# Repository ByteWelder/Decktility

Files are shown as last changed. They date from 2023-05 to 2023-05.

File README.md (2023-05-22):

# Decktility

Decktility is a handheld PC, inspired by [Yarh.io Micro 2](https://yarh.io/),
[uConsole](https://www.clockworkpi.com/uconsole) and various retro handheld PCs.

It is built with a Raspbery Pi CM4 and an 800x480 pixel IPS screen with capacitive touch.
A set of batteries is estimated to provide about 6 hours of power. (\*)

The original build log and learnings can be found on [ByteWelder.com](https://bytewelder.com/posts/2023/05/20/building-a-handheld-pc.html).

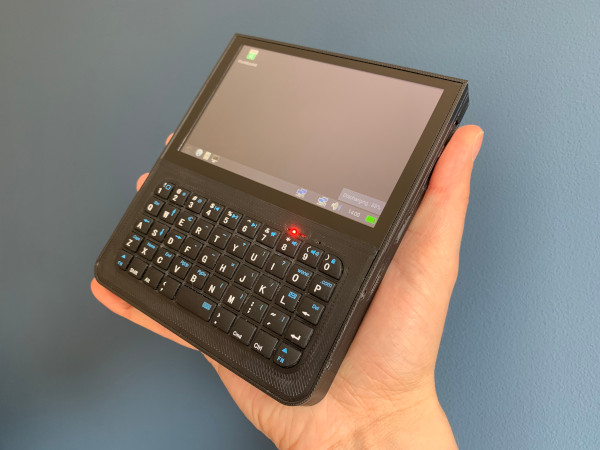
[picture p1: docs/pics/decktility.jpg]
Decktility device mockup


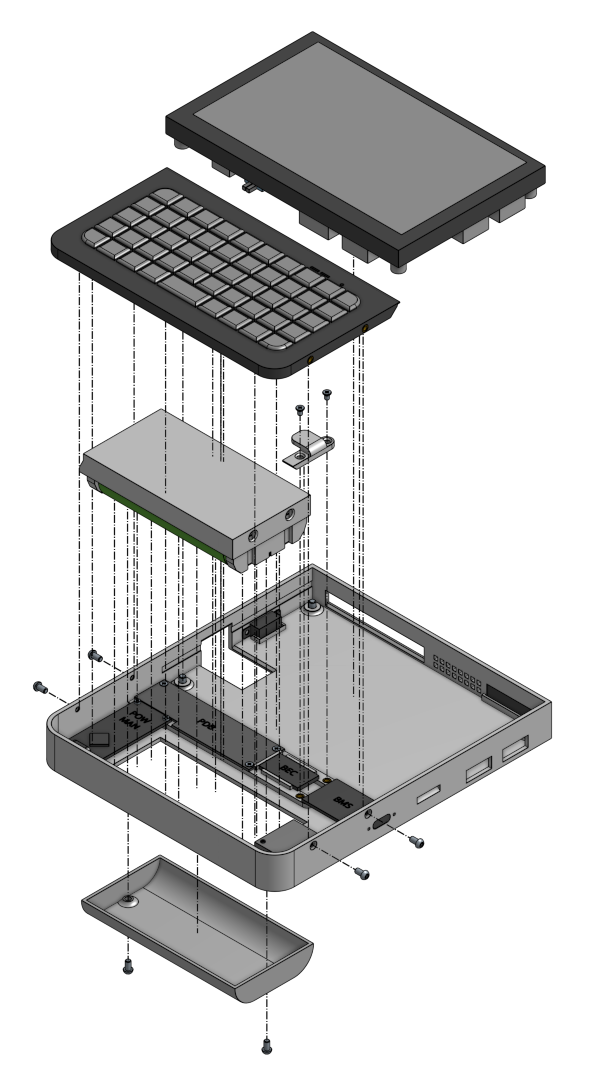
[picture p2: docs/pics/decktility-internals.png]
Decktility device mockup


# Features & Specifications

- Compact design: `124.4 x 144.0 x 16.3 mm` (w x h x d). The battery lid portrudes by `10.2 mm`.
- Weighs approximately `375 g`. (depends on filament weight)
- Powered by a Raspberry Pi CM4 and a BTT Pad 5 (`800x480` resolution with capacitive touch)
- Replaceable batteries
- USB-C charging (~`10 W`)
- Power management

(\*) Using US18650VTC6 cells. Power draw was tested with an idle Discord tab in Chrome.

# Software

## Raspberry Pi

The Pi can be used with [Raspberry Pi OS](https://www.raspberrypi.com/software/) or any other Pi-compatible OS.

Check the to the [Pad 5 Manual](https://github.com/bigtreetech/Raspberry-Pad/tree/master/Pad5) for installing the OS and setting up some of the hardware.

## Arduino Nano / Power Manager

The [Power Manager](./powermanager) controls the power connection to the Pi and the keyboard. Power is enabled/disabled depending on the battery voltage.
The power manager measures battery and charging status, and can send it to the Pi. This enables battery status on the Pi desktop.
If something is not clear - or if you find an error, please open an issue on the GitHub project page.

Check out the [assembly guide](docs/assembling.md) for more details.

# Case

The latest printable parts are in the [printables](printables) folder.

The case is available as open hardware via OnShape:
- [v1.1](https://cad.onshape.com/documents/bcf3b5212bb2ba6496cfe6cf/v/382999b629ab56cddd2b7e21/e/5dfdd5987e1df112fcfa814b)
- [Main/WIP](https://cad.onshape.com/documents/bcf3b5212bb2ba6496cfe6cf/w/d70be68a60b4c80f684ba746/e/f2fb47dfa2dbdc91d7666ed1)

**Warning**: Don't print from the Main branch, because it will possibly have unfinished and/or untested changes.

# Building

Build this project at [your own risk](LICENSE.md).
The build guide might have flaws.
Working with batteries and electronics is not without risk.

- [Bill of materials](docs/bom.md)
- [Printing guide](docs/printing.md)
- [Assembling](docs/assembling.md)

# License

All hardware, software and other content in this project are licensed under `Attribution-ShareAlike 4.0 International (CC BY-SA 4.0)`.

See [LICENSE.md](LICENSE.md) for details. For a short overview and translations go to the [Creative Commons website](https://creativecommons.org/licenses/by-sa/4.0/legalcode).

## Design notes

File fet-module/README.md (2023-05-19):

This is the KiCad project for the FET board, which acts as an electronic switch to turn on/off the hardware depending on available battery power.

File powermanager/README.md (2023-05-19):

This is the Arduino project for the power manager firmware. Open it with Arduino IDE V2.

It is tested with Arduino Nano V3.0, but might also work with other types of Arduino hardware.
Other Arduino hardware is not tested/verified to work, and it will likely not fit on the case mounting points.

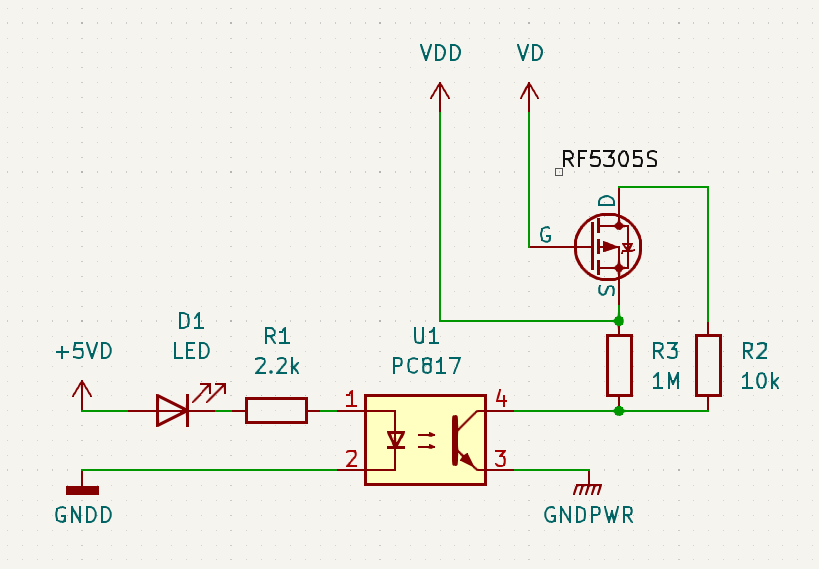
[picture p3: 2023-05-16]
docs/pics/fet-schematic.png

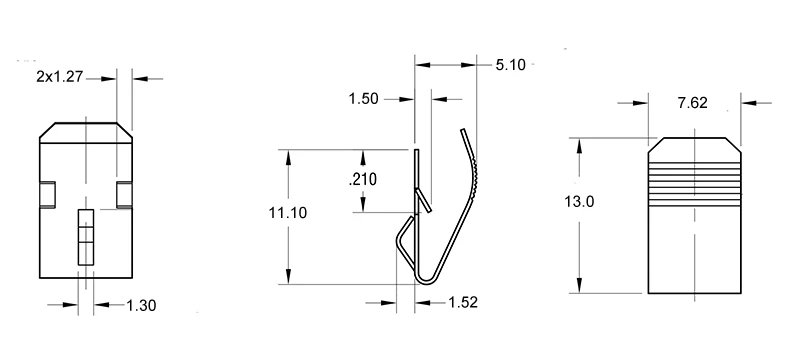
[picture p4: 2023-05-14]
docs/pics/battery-contact-schematic.webp

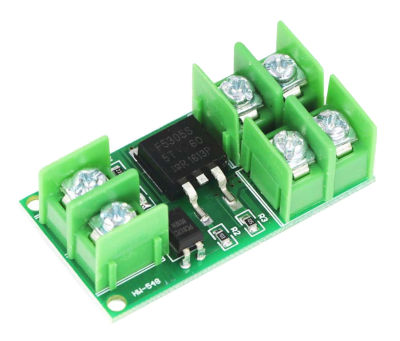
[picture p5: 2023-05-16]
docs/pics/fet-module.jpg

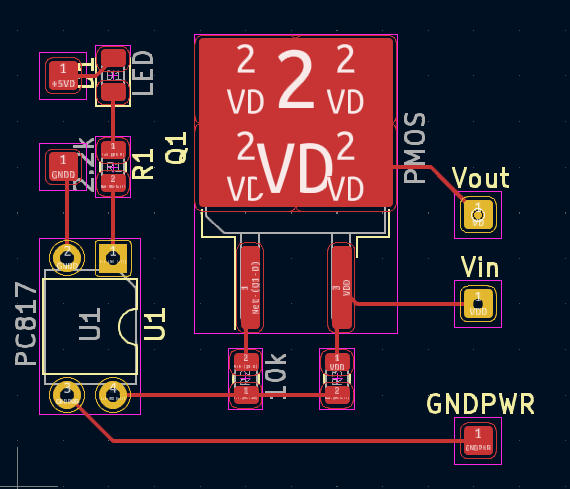
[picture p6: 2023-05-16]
docs/pics/fet-pcb.png

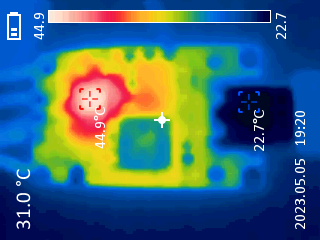
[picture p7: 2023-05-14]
docs/pics/usb-c-bms-heatmap.png

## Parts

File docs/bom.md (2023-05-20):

# Bill of materials for Decktility

I ordered many of the components from AliExpress.
Make sure to double-check that you're ordering the correct item.

- BigTreeTech Pad 5
- Raspberry Pi CM4
- Arduino Nano V3.0
- `5 V` `3 A` step down converter like [this](pics/step-down-top.jpg)
- USB-C 2S battery charger/BMS like [this](pics/usb-c-bms.jpg)
- BlueTooth mini keyboard like [this](pics/bluetooth-keyboard.jpg) (needs modding, see build guide)
- 2x 18650 battery. They **must** be capable of charging with a current of at least `1.5 A`. For example: `US18650VTC6`
- 4x Spring steel 18650 leaf spring battery contact like this [this](pics/battery-contacts.jpg)
- 50x M2 heat insert nut (`2 mm` high, `3.2 mm` wide) (you don't need 50, but you might need more than a single set in case of a failed print)
- 10x M1.4 2mm self-tapping screw (it's best to get a set with various sizes, because printing tolerances vary)
- A set of watch maker screws of various sizes (M1.0, M1.2, M1.4, etc.)
- 4x M2.5 4mm (button or flat head) for Pad 5 mounting (there are cheap sets with M2-M2.5-M3 screws out there)
- 2006 5V fan (`20 x 6 mm`)
- Electrical wire: 24 AWG for power and 28 AWG for silicon. (silicon, not plastic)
- SS12F15 mini slide switch
- Resistors: 1x `2.2M Ohm`, 1x `3.9M Ohm`
- Electronic switch control board (see below)
- Experiment PCB
- (optional) Elastic jewelry wire, 1mm, transparent ('optical fiber' to wire USB charger LEDs to case)
- (optional) JST-SH male and female plugs (for easy detaching I2C wires during development)
- A soldering iron with a long and thin tip to reach the bottom of the Pi header on the PCB. I used a TS100 C1 tip.
- Other soldering gear, 3D printer (or use a 3D printer service online).

## Electronic switch control board

I used a [module](pics/fet-module.jpg) that you can find on AliExpress/Amazon. The module itself is too large, 
so it needed to be transplanted onto an experiment board.
You could either buy such a module and transplant the components, or you can buy the components individually.

Check the assembly guide for the schematics.

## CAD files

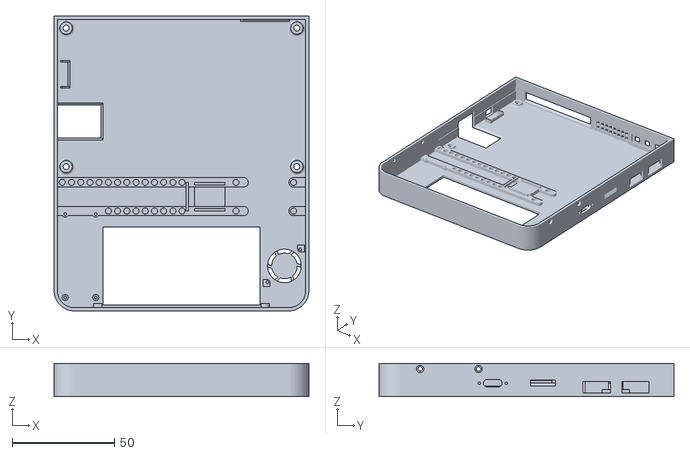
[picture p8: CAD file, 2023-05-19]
printables/Main Case.stl
124.4 x 144.0 x 16.3

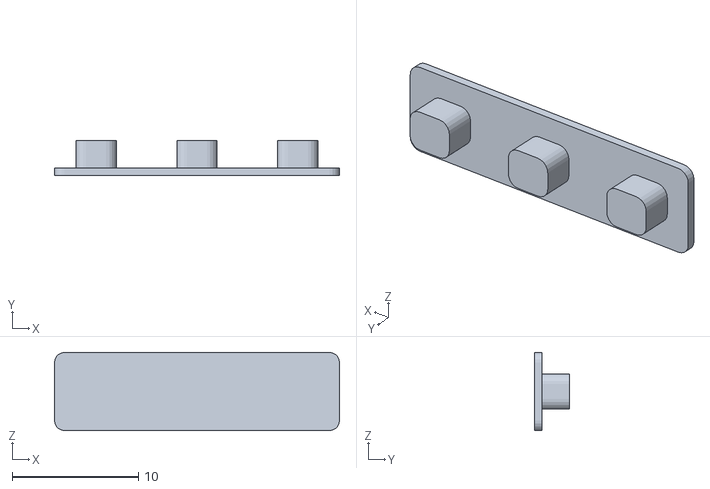
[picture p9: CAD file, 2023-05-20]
printables/Display buttons shim.stl
22.6 x 2.80 x 6.20

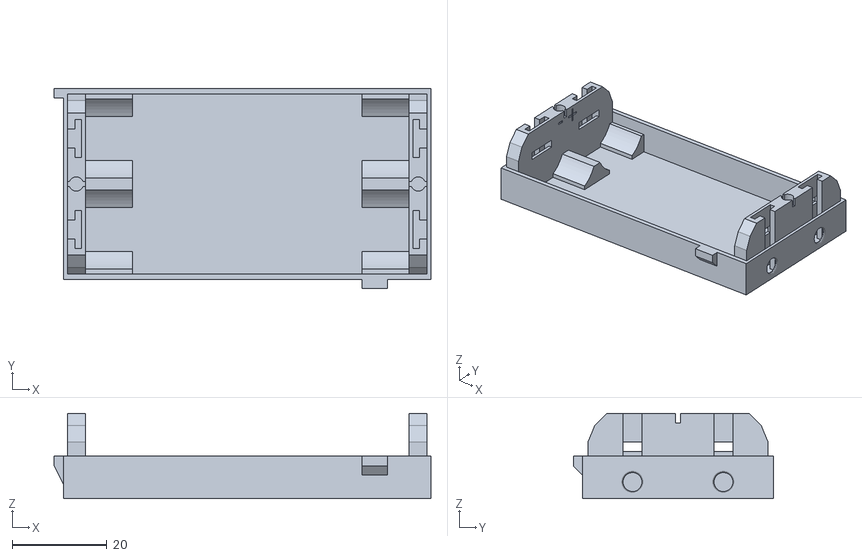
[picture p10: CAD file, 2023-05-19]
printables/Battery Tray.stl
79.6 x 42.3 x 18.0

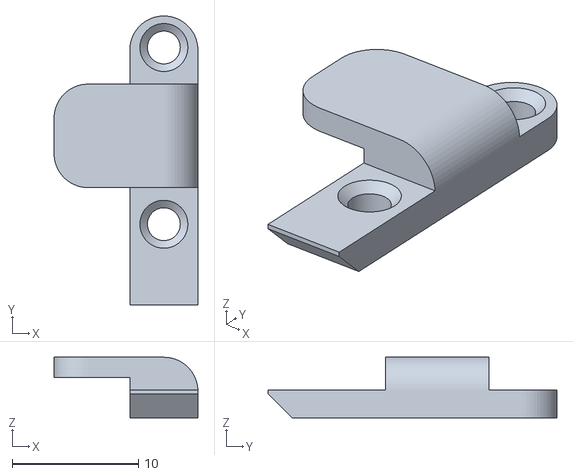
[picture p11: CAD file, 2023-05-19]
printables/Retainer.stl
11.4 x 22.9 x 4.80

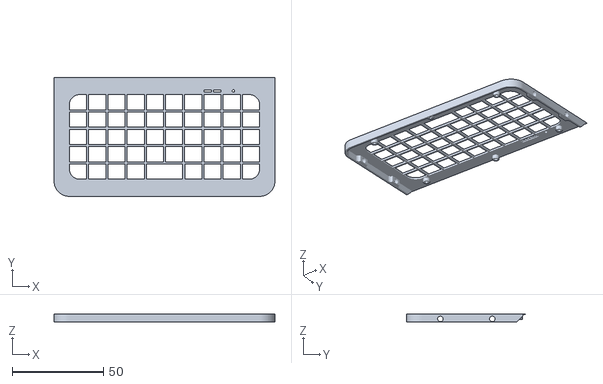
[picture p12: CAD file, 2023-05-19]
printables/Keyboard Panel.stl
121.2 x 65.1 x 4.50

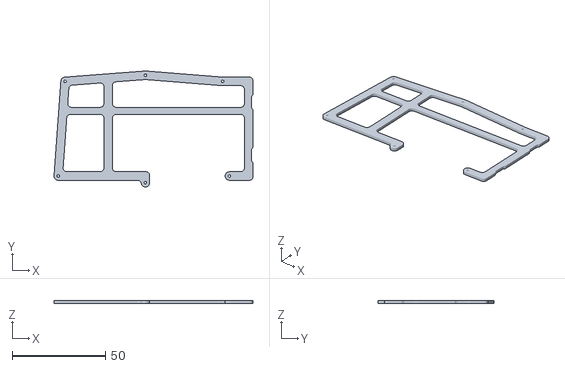
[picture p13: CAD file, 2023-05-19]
printables/Keyboard Retainer.stl
106.8 x 62.3 x 1.60

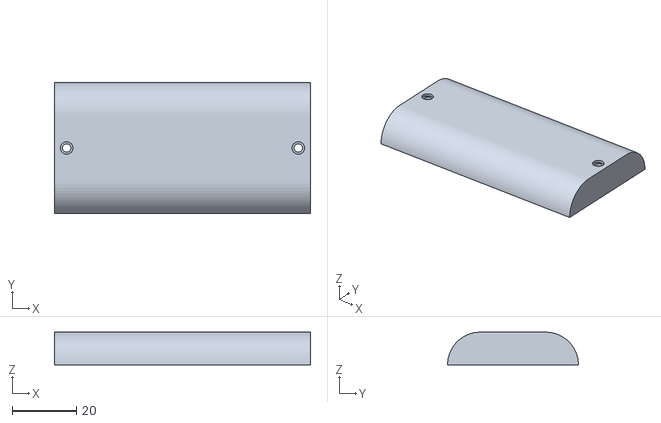
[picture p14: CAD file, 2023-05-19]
printables/Battery Cover.stl
79.8 x 40.8 x 10.2

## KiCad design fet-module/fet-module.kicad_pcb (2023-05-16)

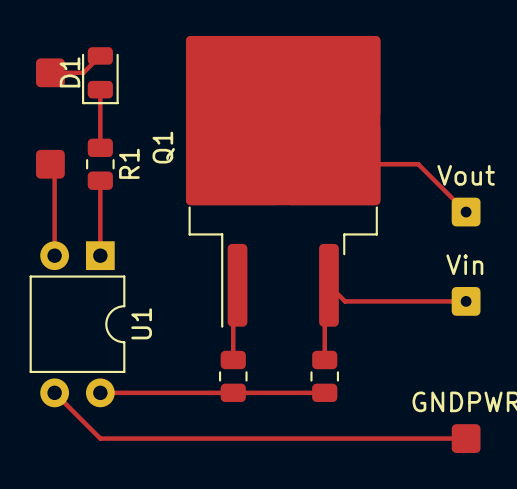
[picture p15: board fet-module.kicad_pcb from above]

Board: 2 copper layers, 11 parts (0 on the bottom side), 9 nets.

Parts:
+5VD: SolderWire-0.1sqmm_1x01_D0.4mm_OD1mm
D1: LED; LED_0805_2012Metric
GNDD: SolderWire-0.1sqmm_1x01_D0.4mm_OD1mm
GNDPWR: SolderWire-0.1sqmm_1x01_D0.4mm_OD1mm
Q1: PMOS; TO-263-2
R1: 2.2k; R_0805_2012Metric
R2: 10k; R_0805_2012Metric
R3: 1M; R_0805_2012Metric
U1: PC817; DIP-4_W7.62mm
Vin: SolderWire-0.1sqmm_1x01_D0.4mm_OD1mm
Vout: SolderWire-0.1sqmm_1x01_D0.4mm_OD1mm

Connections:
+5VD: +5VD.1, D1.2 (A)
GNDD: GNDD.1, U1.2
GNDPWR: GNDPWR.1, U1.3
unnamed: D1.1 (K), R1.1
unnamed: Q1.1 (D), R2.2
unnamed: R1.2, U1.1
unnamed: R2.1, R3.2, U1.4
VD: Q1.2 (G), Vout.1
VDD: Q1.3 (S), R3.1, Vin.1

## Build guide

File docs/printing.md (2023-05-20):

# Printing Guidelines for Decktility

The settings below are based on what I used in SuperSlicer (~PrusaSlicer).
They might (not) translate to other slicer software.

If you don't own a 3D printer yourself, you can use an [online service](https://duckduckgo.com/?t=ffab&q=online+3d+printing+service&ia=web).

The parts can be found in the [printables folder](../printables).

## Filament

If your 3D printer does not have an enclosure, use PETG or PCTG.
I prefer using ASA (with ABS/ABS+ as alternative).

Avoid using PLA or other similar low-temperature filaments:
The BMS can get hot (`45 C`, measured outside the case).
There is active cooling, but if the fan is defect, it might heat up the plastic and warp it.

## Printing

Some parts are exported from CAD upside-down and need to be flipped `180 degrees`.

You can print with layer height of `0.2 mm` or finer and a `0.4 mm` nozzle.

### PCB Bracket

Print in normal orientation with build plate supports.

### Battery Cover

Rotate it 90 degrees over the Y axis so it stands up on its side.
You need supports along the edge on this inside.
I painted them on manually, because they get attached to the inner wall.
Alternatively, you can use `Supports: Everywhere`.

Make sure you clean up the inside thoroughly, so it fits on the case.

### Main Case

Note that the walls are relatively thin and weaken the case near connector holes.
This means that your wall adhesion has to be good. Ensure you're running your filament at a high enough
temperature for the speed you're printing at. If you calibrated your filament to work at a minimum
tempearture, you might have to raise it to create sufficient strength.

Consider changing the the top layer fill patern to `Concentric`. This will give you smoother top surface quality,
both for mounting components and for the top edge of the case.

When printing the main case with ASA, I slice with manually added supports only. I place these supports at:
- The counterbores on the back (the ones for mounting the display)
- The ethernet bridging part
- The Pi's IO connector on the back

When printing with ASA, disable bridging fan speed to avoid adhesion problems near the connector openings.
Otherwise, layers might split off when placing the display into the case.

### Display Buttons Shim

This is printed in TPU. I used 95A shore hardness.
Use a layer height of `0.10 mm` and ensure you have sufficient adhesion by printing at a high enough temperature.
The top infill type can be set to `Concentric` for a better finish.

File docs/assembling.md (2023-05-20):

# Assembling Decktility

**Note:** This document is a work in progress.

## Power Manager / Arduino Nano

### Firmware 

You can build the project with `Arduino IDE V2`. Change `config.h` to your liking.

The default (and only) battery and discharge profile is for a Murata VT6 3120 mAh cell.
You can leave it in place, but you can also make your own. It is set in `powermanager.ino`
and the default profile is in `battery.cpp`.

### Pinout

The default pins on the Arduino are as follows:
- `Vbat` is measured at pin `A0`.
- Charge state is measured at pin `D2`. It connects to the LED connector on the USB-C BMS board. This is marked as `LED` on the back or `D` on the front of the PCB.
- The power enable pin for the mosfet is wired to `D3`.
- `Vin` and `Gnd` are wired to the common ground and to the switch that connects to the `5 V` of the step down converter.
- `A4` is `SDA` and `A5` is `SDL`. They connect to the Pi on pin 3 (`SDA`) and pin 5 (`SDL`). SDA to SDA, and SDL to SDL.

If you use an alternative I2C bus on the Pi, the driver won't scan that bus and it won't work.

### Calibrating the voltage

Update the value for `VBAT_ADC_MAX_BATTERY_PIN_VOLTAGE` depending on the resistors you chose.
You must use high resistance values to reduce the current that leaks, as this wire is always connected to the battery.
Make sure the pin on the Arduino never gets more than `5V`.

I calibrate it as follows:
- Upload firmare with `BATTERY_STATE_LOG` enabled in `config.h`
- Disconnect USB from Arduino
- Measure battery voltage with multimeter
- Reconnect USB to Arduino and observe the voltage readout.
- Check the difference relative to what you expect, and use that factor to multiply or divide with `VBAT_ADC_MAX_BATTERY_PIN_VOLTAGE`
- Repeat the procedure to verify

### Raspberry Pi

Add to the following to `/boot/config.txt`:

```
dtoverlay=ltc294x,ltc2942,resistor-sense=50,prescaler-exponent=128
```

### Debugging I2C

Manually activate the driver:

```bash
modprobe ltc2941-battery-gauge && lsmod | grep ltc
```

Manually deactiate the driver:

```bash
rmmod ltc2941-battery-gauge
```

Check driver status messages:

```bash
dmesg
```

Retrieve the battery status on the Pi with [ic2test.sh](../scripts/i2ctest.sh).

Kernel driver reference: https://github.com/torvalds/linux/blob/master/drivers/power/supply/ltc2941-battery-gauge.c

Implementation reference: https://github.com/MacroYau/LTC2942-Arduino-Library

Datasheet: https://www.analog.com/media/en/technical-documentation/data-sheets/ltc2941.pdf

## Keyboard mod

The keyboard comes with a Lithium battery installed, but I needed it to work with `5 V`.
I copied the idea from [Yarh.io](https://yarh.io/yarh-io-m2.html), but I'll elaborate on it here.

- Desolder the lipo.
- Desolder the USB connector. I ended up cutting it off entirely, including the PCB part under it that sticks out.
- Connect the `5 V` pad from the USB connector to the `+` connector where the lipo was. You can use the pad of the USB connector, but I found it easier to solder directly to the top of `R20`.
- Desolder and remove `U6`. The 2 pads on the bottom right should be soldered together.

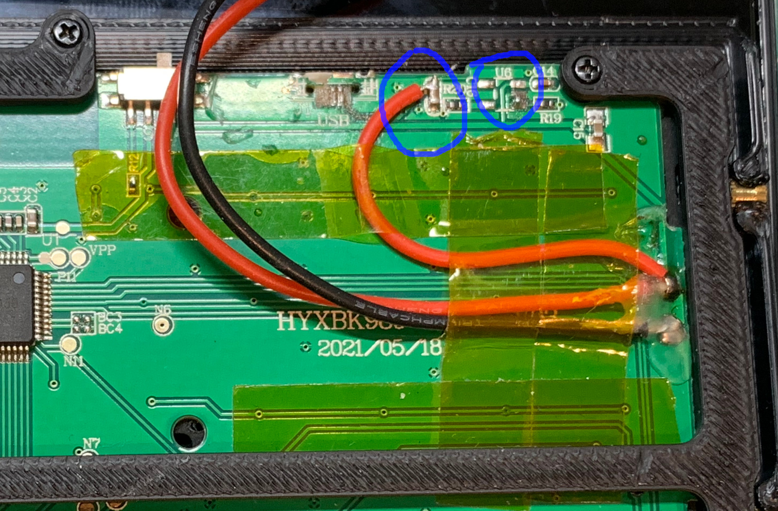
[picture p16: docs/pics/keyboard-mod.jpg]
keyboard PCB modded


## FET module

Build it according to the [schematic](pics/fet-schematic.png) and [PCB placement](pics/fet-pcb.png).

## Heat inserts

Insert heat inserts:

- In the case
- To the sides of the keyboard top panel
- On the top of the battery container 

## Fan

The fan wires are made of plastic. which can melt when soldering. The wires are stiff and runs past the BMS that can get hot.
It is advised to cut the wires short and extend back to the desired length with AWG28 silicon wire. Don't forget to add some heat srhink.

## Wiring

Wiring is divided into steps, to make it easier to comprehend.
Make sure you check continuity on the wires before powering on - especially to make sure there are no short-circuits.
Make sure to verify the functionality at each step before continueing to the next.

Double-check your soldering joints, to make sure they are safe. You don't want wires to come loose while you use the device.

### Wiring step 1: battery to BMS

The BMS is connected first. Test if the battery is charging properly.

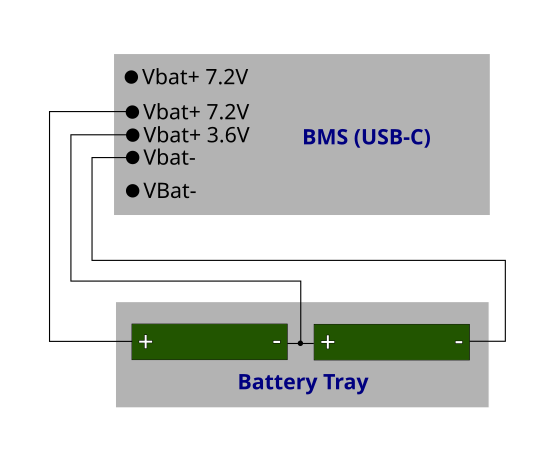
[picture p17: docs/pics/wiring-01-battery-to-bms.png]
battery to bms wiring schematic


### Wiring step 2: BMS to BEC

Now that we have battery power, we'll connect the BEC to step it down to 5V.

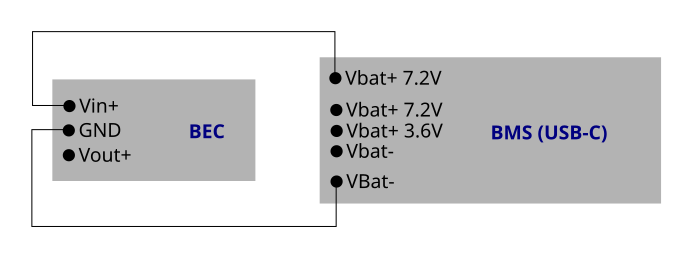
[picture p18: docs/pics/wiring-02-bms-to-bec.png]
bms to bec wiring schematic


### Wiring step 3: power

There rest of the power is connected now.
The switch powers on the Arduino, while the Arduino powers the FET, which powers the rest of the devices.

The power wiring on the Pi is done directly on the black pin header near the PCB.
I start by adding some solder to the base of the relevant pins, before adding the wiring.
Make sure the wiring is attached properly, because you don't want it to come loose and create a short-circuit.

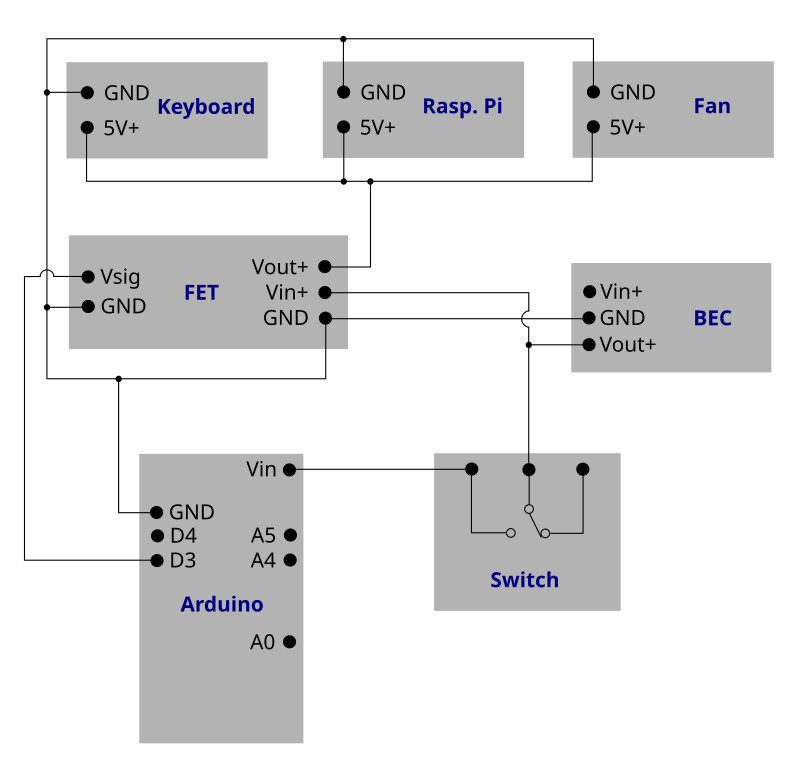
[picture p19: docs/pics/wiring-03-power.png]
general power wiring schematic


### Wiring step 4: Arduino

The remaining wires for the Arduino are now connected. It includes I2C, voltage measurement and charging status sensing.

I used `3.9M Ohm` for `R1` and `2.2M Ohm` for `R2`. 
If you use different resistor values, you must tweak the firmware settings in `config.h` of the firmware project.
You must use high resistance values to reduce the current that leaks, as this wire is always connected to the battery.
Make sure the pin on the Arduino never gets more than `5V`.

The Pi wiring for I2C is done directly on the black header connector pins.
I used a long and thin TS100 C1 tip to reach these pins.

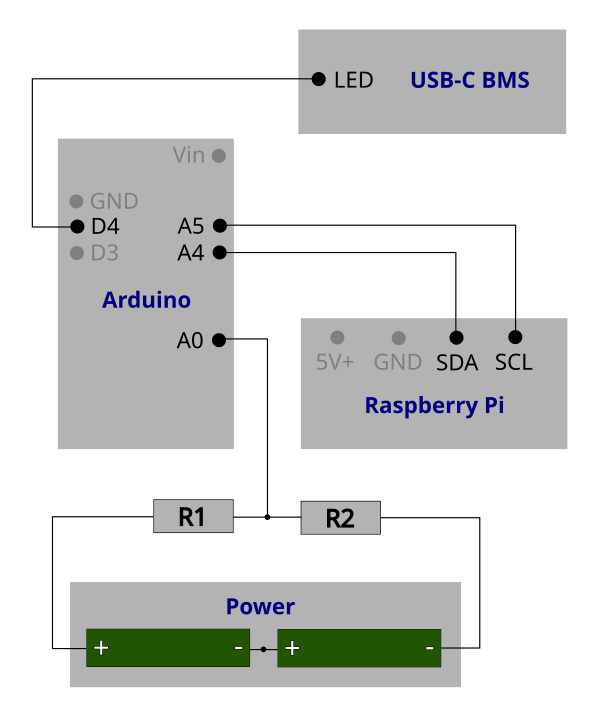
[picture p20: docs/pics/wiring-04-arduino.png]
remaining arduino wiring schematic


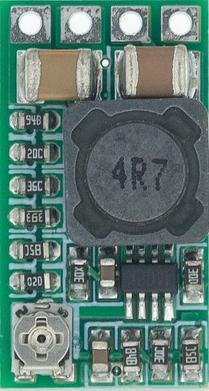
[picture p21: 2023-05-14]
docs/pics/step-down-top.jpg

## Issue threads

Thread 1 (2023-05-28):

Discussions section

vault-thirteen, 2023-05-28:
Hello there !

I have always been thinking about a portable pocket PC (or a PDA, as they were called several years ago) having a power supply of several 18650 batteries. Me personally thinks that a lot of people are interested in your project as well as me. It would be great to add a `Discussions` section to your repository to allow people to discuss the **Decktility**.

Thank you for what you are doing.

KenVanHoeylandt, 2023-05-28:
Thank you for your interest and for the suggestion. I didn't know of that feature until your message. I've activated it on the project.

Closed 2023-05-28.

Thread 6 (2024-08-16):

Arduino wiring question and battery config.

pterodyne, 2024-08-16:
Hey, great project.  Im actually just using the battery monitoring part for my DIY Laptop.  My system will use a Radxa Rockchip CM5 unit.

Anyway, Im not using the same BMS as you, but rather a 8A 2S unit with VIN rather than USB-C and a 100W USB C trigger board with a diode to drop the voltage from the hard wired 9V to 8.4.  So I do have an LED that lights up when USB C is plugged in.

In reading your block diagram Im assuming that you are jumping off the LED to provide a trigger to the "Is charging" state.  Do you see any reason why my difference would be a problem?  How did you wire it?  Which side of the LED?  Or did you remove the LED?

Another question would be, Im using 2X5000Mah Lithium pouch cells, but otherwise they are the same chemistry as 18650, but with a larger capacity.  Do I just adjust the discharge curves and capacity?  I saw the part for calibration but I assuming I need to adjust all the parameters for the battery.

Oh, one other point of confusion. You mention a BEC at one point and show a picture of a stepdown converter in the BOM.  Im using a 6A UBEC meant for a drone, but it can do wide input, and 6A@5V so suitable for my needs.  It will cut off the batttery when below the voltage threshold unlike a buck converter.  Saves the battery in the event the software doesn't shut it down or the system is crashed.

thanks for looking

Bryan

pterodyne, 2024-08-16:
I found where you mention the the pads for the LED on the BMS you chose, so Maybe Ill try to use the LED as a trigger for my setup..

KenVanHoeylandt, 2024-08-16:
I did indeed use a specific pad for that (the "D" one at https://www.aliexpress.com/item/1005004682732678.html).

>  Do I just adjust the discharge curves and capacity? I saw the part for calibration but I assuming I need to adjust all the parameters for the battery.

Yes, you need to adjust all the details for your cells. If the curve is not accurate, the reported battery percentage to the main computer will be inaccurate.

The most important part of the config is `Battery.vCritical`. You must check the data sheets to find the lowest voltage that is safe for your cells. Don't set this lowest voltage as `vCritical`: add a safety margin!
If the battery goes below the critical voltage it might damage the cell. Keep in mind that if the computer is off, the microcontroller for the battery management is still running. My electronics design doesn't allow for shutting off that subsystem currently. I might redesign that in the future.

pterodyne, 2024-08-23:
thanks for replying.  Im working on porting the l294x.dtbo to rockchip, and waiting for the kernel maintainer to turn on the kernel driver for it ([Ubuntu rockchip by Joshua Riek](https://github.com/Joshua-Riek/ubuntu-rockchip)).  Looks like mostly the overlay has compatibility strings for broadcom, which Ive removed, but cannot test until the kernel is updated.  Don't want to deal with custom kernels.  Anyway Ive been playing with it on a Pi5, and have a new question.

Ive been trying to understand just the "chargestate" pin.  I don't have the same board as you for USB input power, but I figured it's just reading the pin led pin going high from your board.  What Im seeing in reality, with no pin connected is it just displaying:

charging: yes
charging: no
charging: yes
charging: no

in the serial console.  Generally toggling back and forth unconnected.  Sometimes if I apply 5v on that pin it changes to yes or no, but doesn't seem to be any rhyme or reason to it.

I did have to use a different pin because Im using an Ardunio Pro Micro. but it definitely does seem to trigger sometimes.  I even tried a different pin from the original one since this arduino is a cheapo and pulled from a box.  The battery sensing works great. If it matters I don't really have it installed I just have a bench supply attached to A0 set to a low voltage 2 or 3V and lowering and raising it changes the battery display on the Pi as expected.  Also I don't have the power switch/FET hooked up yet if it matters. That pin is unused right now.

Thanks

Bryan

KenVanHoeylandt, 2024-08-24:
> and waiting for the kernel maintainer to turn on the kernel driver for it ([Ubuntu rockchip by Joshua Riek](https://github.com/Joshua-Riek/ubuntu-rockchip)). Looks like mostly the overlay has compatibility strings for broadcom, which Ive removed, but cannot test until the kernel is updated.

Assuming it's just a kernel module, you could compile that module and enable it locally.
This was my plan in case Raspberry Pi didn't have any suitable drivers available by default.

> Ive been trying to understand just the "chargestate" pin. I don't have the same board as you for USB input power, but I figured it's just reading the pin led pin going high from your board. What Im seeing in reality, with no pin connected is it just displaying:

Regarding the `chargestate` pin: it's just a high/low input.
If you don't connect it then it will "float" and thus you get random alternating high/low values.
You can connect it to either ground to get a continuously low signal or to constant voltage for a continuously high signal. What voltage is "high" depends on your board: for some that is `3.3 V` and for others it is `5 V`. Make sure you don't apply `5 V` to an input that only tolerates `3.3 V`.

Closed 2025-02-19.

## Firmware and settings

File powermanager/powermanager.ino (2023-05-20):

#include "log.h"
#include "batterystate.h"
#include "chargestate.h"
#include "powerswitch.h"
#include "ltc294x.h"
#include "battery.h"

void setup() {
  logInit();
  log("Init ... ");

  setBattery(murata3120Vtc6);

  ltc294xInit();
  batteryStateInit();
  chargeStateInit();
  powerSwitchInit();

  logLn("done");
  
  batteryStateLog();
}

void loop() {
  batteryStateUpdate();
  chargeStateUpdate();
  powerSwitchUpdate();

  delay(1000);
}

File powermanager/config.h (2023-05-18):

#ifndef CONFIG_H
#define CONFIG_H

#define VBAT_ADC_PIN A0
// Tweak with PSU. See when analog input becomes 1023.
#define VBAT_ADC_MAX_READABLE_PIN_VOLTAGE 4.1f
// Measured between 2 resistors when input voltage is at max (e.g. 8.4V)
#define VBAT_ADC_MAX_BATTERY_PIN_VOLTAGE 3.05f // 0.03
#define VBAT_ADC_MAX_BATTERY_REAL_VOLTAGE 8.4f
#define VBAT_CELL_COUNT 2

#define CHARGE_STATE_PIN 2

#define POWER_ENABLE_PIN 3

#define DEBUG
// #define BATTERY_STATE_LOG
#define CHARGE_STATE_LOG
#define POWER_SWITCH_LOG
// #define I2C_LOG

#endif

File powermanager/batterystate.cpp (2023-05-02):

#include <Arduino.h>
#include "log.h"
#include "config.h"
#include "batterystate.h"

#define ADC_RESOLUTION 1023.f

// Entry count should be low enough to get updates often (1 entry per second),
// but high enough so that the voltage readings don't fluctuate too much.
// Too many items might result in slow response to low battery. This would only
// be problematic with high current draw.
#define VOLTAGE_HISTORY_ENTRIES 7
float voltageHistory[VOLTAGE_HISTORY_ENTRIES];
uint8_t voltageHistoryIndex = 0;

void storeCurrentVoltageInHistory() {
  voltageHistoryIndex++;
  if (voltageHistoryIndex > (VOLTAGE_HISTORY_ENTRIES - 1)) {
    voltageHistoryIndex = 0;
  }
  voltageHistory[voltageHistoryIndex] = batteryStateGetVoltageNow();
}

void batteryStateInit() {
  batteryStateGetVoltageNow(); // discard first result because it is inaccurate
  // Fill the buffer with readings
  for (int i=0; i<VOLTAGE_HISTORY_ENTRIES; ++i) {
    storeCurrentVoltageInHistory();
  }
}

void batteryStateUpdate() {
  storeCurrentVoltageInHistory();

  #ifdef BATTERY_STATE_LOG
    batteryStateLog();
  #endif
}

void batteryStateLog() {
    log("battery: ");
    log(batteryStateGetVoltageAverage());
    logLn(" V");
}

float batteryStateGetVoltageAverage() {
  float sum = 0.0f;
  for (int i=0; i<VOLTAGE_HISTORY_ENTRIES; ++i) { 
    sum += voltageHistory[i];
  } 
  return sum / (float)VOLTAGE_HISTORY_ENTRIES;
}

float batteryStateGetVoltageNow() {
    // read the value from the sensor:
  int adcValue = analogRead(VBAT_ADC_PIN);
  float adcValueScaled = (float)adcValue / ADC_RESOLUTION;
  float voltageReadOnPin = adcValueScaled * VBAT_ADC_MAX_READABLE_PIN_VOLTAGE;
  float voltage = voltageReadOnPin / VBAT_ADC_MAX_BATTERY_PIN_VOLTAGE * VBAT_ADC_MAX_BATTERY_REAL_VOLTAGE;
  return voltage;
}

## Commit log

2023-05-02 added powermanager and powermanager-client
2023-05-04 updated BOM
2023-05-12 printing tips
2023-05-13 battery life
2023-05-14 fixed bom pics links
2023-05-14 added power manager info
2023-05-16 new fet docs
    [fet-module.kicad_pcb, fet-module.kicad_sch]
2023-05-18 updated power manager and docs
2023-05-18 firmware fixes for battery capacity value
    [config.h, ltc294x.cpp]
2023-05-18 added test script for i2c
2023-05-19 fix for deleted header
    [ltc294x.cpp]
2023-05-19 update for battery i2c fixes
2023-05-19 release v1.0
    [Battery Cover.stl, Battery Tray.stl, Display buttons shim.stl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]
2023-05-19 added fan instructions
2023-05-19 improved wording on BMS
2023-05-20 added wiring docs
2023-05-20 3d printing updates
2023-05-20 added pi soldering tips
2023-05-20 display buttons shim fix and docs
    [Display buttons shim.stl]
2023-05-22 clarify battery life better
